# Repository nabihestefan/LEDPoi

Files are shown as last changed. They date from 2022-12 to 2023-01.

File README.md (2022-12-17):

# LED Prop Module
#### Nabih Estefan & Olivia Jo Bradley
Main Photo

For this project, we wanted to create a LED Prop Module by creating a battery powered PCB with a microcontroller, LEDs, an accelerometer, and buttons ,which would be enclosed in a clear capsule. 
Both of us are members of the Olin Fire Arts Club, and enjoy springing and performing with fire. Spinning fire is dangerous, and fire props are delicate, so we try to avoid practicing and trying new tricks with them. The solution to this is an LED version of the prop that is more durable and less dangerous than fire props, but is still exciting and aesthetic, so it can be used to perform with if desired.
This project requires a board with a battery management system, bright RGBW LEDs, an accelerometer (to react to the movements of spinning), a button to change modes, and a microcontroller that can run the code to make all of these work. As a stretch goal, we also wanted to add a bluetooth module to the board so we could connect and sync the colors and patterns of multiple modules. 

This repository holds the [Software](Software/), [Electrical](Electrical/) and [CAD](CAD/) files required to fabricate and assemble the board and casing designed by us and teh code to run the Prop Module. There is also a [images](images/) folder that contains images of the prototype and demo videos of the prop module in use. Finally, it also has our [Proposal](Proposal.pdf) and [Report](Report.pdf) detailing how we designed and built the Prop module.

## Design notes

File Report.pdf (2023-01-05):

# LED Prop Module

Eclectronics Final Report – Olivia Jo Bradley & Nabih Estefan

## Introduction

For this project, we wanted to create a LED Prop Module by creating a battery powered PCB with a microcontroller, LEDs, an accelerometer, and buttons ,which would be enclosed in a clear capsule.
Both of us are members of the Olin Fire Arts Club, and enjoy springing and performing with fire. Spinning fire is dangerous, and fire props are delicate, so we try to avoid practicing and trying new tricks with them. The solution to this is an LED version of the prop that is more durable and less dangerous than fire props, but is still exciting and aesthetic, so it can be used to perform with if desired.
This project requires a board with a battery management system, bright RGBW LEDs, an accelerometer (to react to the movements of spinning), a button to change modes, and a microcontroller that can run the code to make all of these work. As a stretch goal, we also wanted to add a bluetooth module to the board so we could connect and sync the colors and patterns of multiple modules.

## Selecting Parts

The process for speccing out the parts for our board was, unsurprisingly, very easy. The reason we say unsurprising is because most of the parts we needed for the board we chose through different projects we or Brad had done before. We based our project off of Mini-Project 3, including all of its components, so we focused on designing the 5 new sections we needed for the board:
1. Battery + Battery Management System
2. Wireless Module
3. Accelerometer
4. LEDs
5. Color Change Button
The first three were very easy because Brad showed us one of his old projects that also included these components, and were able to pull parts from that. The color change button was very easy to technically spec, so we focused on choosing a button that would fit the final aesthetic of the module, and went with an arcade style clear button. Finally, the LEDs took us the longest because we had to find LEDs that were bright enough but didn’t require an insane amount of voltage and/or current to run. We decided Neopixels were the best bet and eventually we found some side-lit ones that would allow us to shine lights on two sides of our board.

## Making the Schematic

Below, you can see the schematic we ended up designing for our LED Prop Module. The schematic work was surprisingly easy because of a couple of reasons, very similar to the reasons choosing parts was easy. For starters, we had a pretty big baseline with the Mini-Project 3. The other 5 big components that needed to be added to the board were:
1. Battery + Battery Management System
2. Wireless Module
3. Accelerometer
4. LEDs
5. Color Change Button
The first three were very easy to add because Brad helped us understand how they worked with one of his older schematics for a separate project that used these components, so we were able to just bring those over. The LEDs were also very easy to add because we only needed a single pin from the RP2040, and then we followed the schematic from the datasheet. Finally, the color change button was probably the easiest, since it’s just a button connected to the RP2040, and we have implemented surface mount versions in the past few mini projects. This meant that we were able to get a schematic done very fast, and were able to move onto the layout quickly.

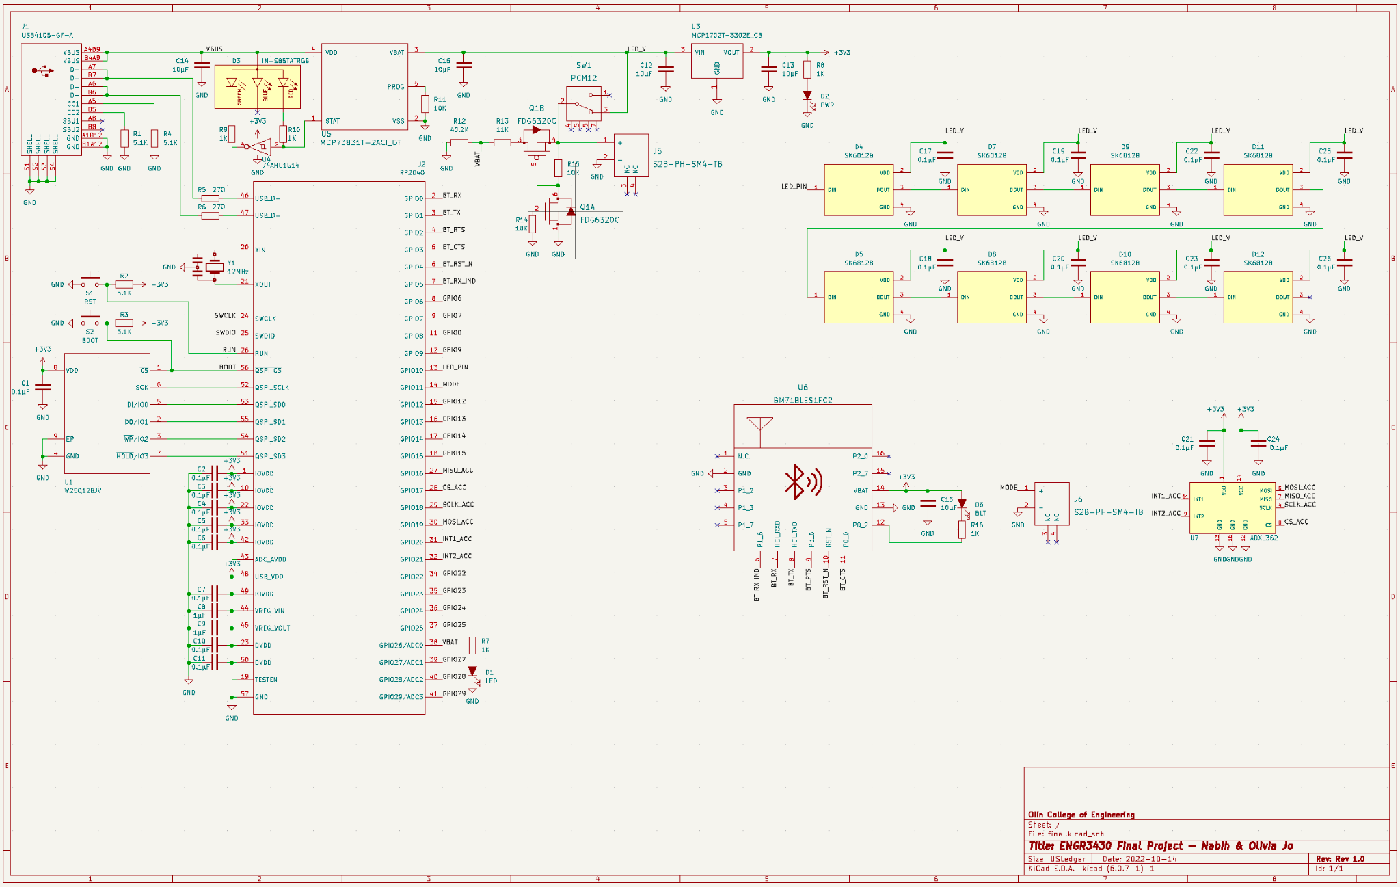
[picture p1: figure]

## Making the Layout

To the right you can see the final layout of our board. Once again, a lot of the general knowledge from Mini-Project 3 was brought onto this board, which resulted in it only really needing 2 revisions. Our first revision was getting the components down and fitting into the tiny board we gave ourselves. This board is very small because we didn’t want to have to handle a giant board for a prop module, since those are supposed to be nimble and small. Below the board you can see the diameter of our battery for context. While we were trying to make a smaller board, we did limit our minimum component size to 0603 components due to our experiences with Mini-Project 3.

## Building the Board

Once we got the physical boards and parts after thanksgiving,

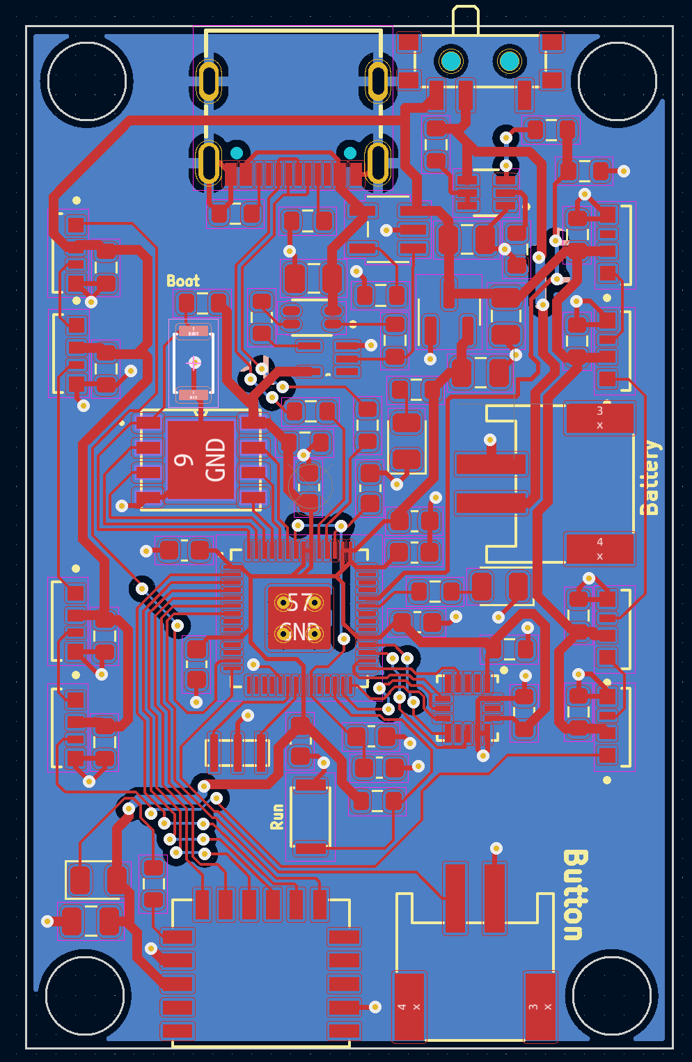
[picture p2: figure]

we set to building our board. We used the stencil that Brad provided, and created component sheets to organize our strips of parts. Our first iteration of the board had an unattached RP2040, and even though we tried to hand-solder it, we weren't able to get it to work. However,our second version worked perfectly, and we were able to run the LED code on it immediately!

## Code

Once we had a working board, there were 3 steps to the code development for the board. The first step was to get the LEDs to light up a single color which was extremely non-trivial since there is a micropython neopixel library which makes this extremely easy. The second step was getting the button to work to change colors. Theoretically this should have been non-trivial, and in code it was, but we had bought the wrong JST PH 2.0 connector cables for the button so we stalled here for a while. Finally, the third part was to implement the code to read data off of the accelerometer. This was extremely hard because the accelerometer works on a SPI bus, something neither of us had ever done. Eventually, we figured out the code we needed for it, but turns out that trying to compile the code needed through Thonny (the IDE we had been using to flash the RP2040 after it was the only working option in MP3) is basically impossible because there is no support for external libraries. Eventually we found an ADXL362 library that was perfect for what we needed, and it worked with Micropython! Sadly, we couldn’t install all the needed dependencies on the RP2040, so we had to turn back and look into the built in SPI library and try to get that one to work. We eventually got code that theoretically should work, but couldn’t figure out why it wasn’t and we ran out of time. Currently, the code in the github repo has the implementation for mode changes with the button and has theoretically working code for the accelerometer changing the blinking speed, we believe that the error with the accelerometer comes from the physical part on the board but we didn’t have time to assemble a new one. This means our Software folder currently has 2 versions: main.py and main_accel.py. The first one is the one we’re currently using that has no accelerometer code, and the second one contains the accelerometer code.

## Building the Enclosure

The enclosure for our LED Poi module needed to be semi transparent and contain all the necessary components, and hopefully easy to interact with (charge, press the button to change modes), connect to a rope handle of some sort, have a comparable weight to a fire prop, and be robust. To create the module, we instantly turned to 3d printing as it would allow us to use transparent materials, create unique shapes, and iterate quickly. We chose to make the enclosure out of clear resin, as it is a mostly transparent material, diffuses light nicely, and prints solid, providing more weight. We started with a traditional cylinder, making sure the button, board, and battery all fit. Once this was confirmed, we iterated and created a form with a more natural, rounded shape, as well as some modifications to make it print easier. The final enclosure can be seen below.

## Final State

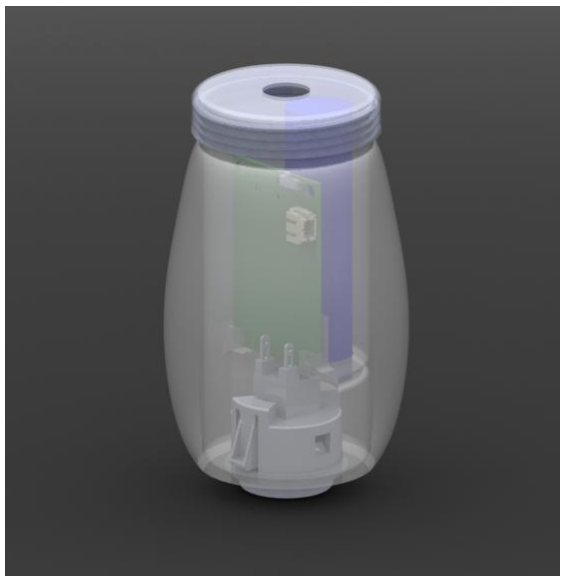
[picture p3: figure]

This all means that the final state of our project is a self-encased board with battery and button that has different blinking modes for spinning as a prop. Sadly, it has no accelerometer reaction, but assembling a new board would most likely solve this problem.

## Project Experience

We both had a lot of fun with this project, as we were both personally motivated and excited about the prop module we were making. We both came into this project wanting to become better at board assembly, as Mini Project 3 took far too many attempts. We were able to mostly complete this, as we were much better at connecting the RP2040 and only had to use 2 boards to get our first working board. We also got much better at selecting components, as we had to select and design for our LEDs using datasheets, something Olivia Jo was interested in doing, and she was able to complete this learning goal. While we were not able to complete all of our goals and stretch goals for the module, we were able to complete our learning goals, expand our knowledge, and create a working prototype.

The link to our github repository that contains all of the elements we created in this project is: https://github.com/nabihestefan/LEDPoi

This includes a schematic of our system, CAD renderings, our code, a bill of materials, photographs of our system, and our photographs and videos of our prototype.

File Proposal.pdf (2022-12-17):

Nabih Estefan & Olivia Jo Bradley

# LED Spinnable Prop

The plan is to build a board with the encasing around it that is able to act as a fully functioning LED Prop. This involves the following:

The Board will have an internal rechargeable battery, and a set of functions for different light modes for spinning with different sub-modes depending on acceleration, and a set of big LEDs that will be visible during the night.
Big features:
- Bright LEDs for display
- Different modes that can be changed using a easy-to-access button
- Rechargeable Battery
- Reaction to Accelerometer on light modes

Basically, this would be a board similar to the one in MP3 that has the following major components:

- USB-C Port
- Data transfer and maybe charging the battery?
- Microcontroller
- We can use the RP2040, might have to do some fun transistor things for LEDs
- An internal Singular Lipo battery
- 3.5-4.3V, 750mAh (or something close, this are the specs of existing LED props) (also hopefully rechargeable with the same USB-C port)
- An extra button that has two different types of clicks (hopefully, or at least two functionalities in press and hold)
- Or worst case one button and one switch, button for modes, switch for on/off
- A bigger set of RGB LEDs that have much higher illumination and can hopefully have different settings of brightness
- Dialight RBG Surface Mount LEDs probably, may use Neopixel instead, need to do some extra research before choosing
- A accelerometer that is able to differentiate between stable and moving poi so that the light modes will change
- 3 axis - Brad has a set of them we could use (Analog Devices)
- Stretch: Having a wireless module to communicate/sync two sets of poi
- RN4871

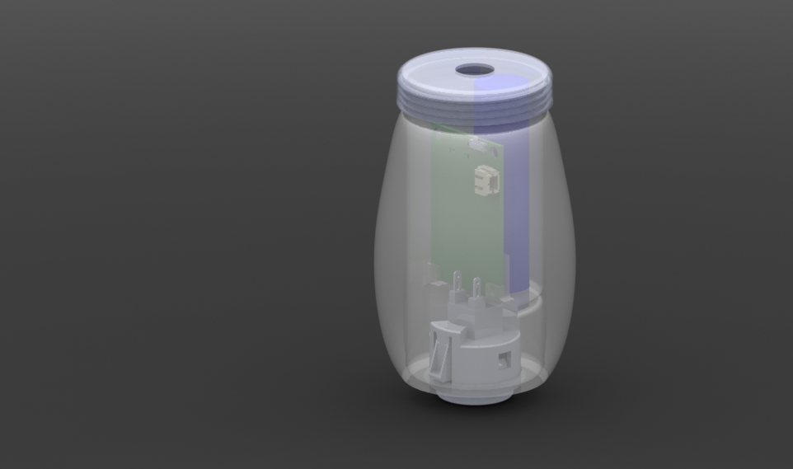
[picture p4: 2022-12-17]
Enclosure CAD/Render.JPG

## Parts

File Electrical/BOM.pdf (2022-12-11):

Description | Quantity in board | How many to order | Cost per part | Order cost | Manufacurer Part # | Catalog #
Arcade Button - 30mm Translucent Clear | 1 | 4 | $5.95 | $23.80 | Product ID: 471 | Adafruit
Arcade Button Quick-Connect Wire Pairs - 0.11" (10 pack) | 1 | 1 | $4.95 | $4.95 | Product ID: 1152 | Adafruit
Lithium Ion Cylindrical Battery - 3.7v 2200mAh | 1 | 4 | $9.95 | $39.80 | ICR18650 2200mAh 3.7V | Adafruit
NeoPixel Side-Light RGB LED w/ Integrated Driver Chip - 10-pack - SK6812B 4020 | 8 | 8 | $3.95 | $31.60 | Product ID: 4691 | Adafruit
0603 ±1% 1/10-W 1-kΩ resistor | 5 | 50 | N/A | N/A | RC0603FR-071KL | 311-1.00KHRCT-ND
0603 ±1% 1/10-W 27.4-Ω resistor | 2 | 20 | N/A | N/A | RC0603FR-0727R4L | 311-27.4HRCT-ND
0603 ±1% 1/10-W 5.1-kΩ resistor | 2 | 20 | N/A | N/A | ERJ-3EKF5101V | P5.10KHCT-ND
0603 25-V X7R 1-µF ceramic capacitor | 2 | 20 | N/A | N/A | CL10B105KA8NNNC | 1276-1184-1-ND
0603 50-V X7R 0.1-µF ceramic capacitor | 15 | 150 | N/A | N/A | CL10B104JB8NNNC | 1276-1033-1-ND
0805 25-V X5R 10-µF ceramic capacitor | 5 | 50 | N/A | N/A | CC0805KKX5R8BB106 | 311-1869-1-ND
0805 blue LED | 1 | 10 | N/A | N/A | LTST-C170TBKT | 160-1579-1-ND
0805 green LED | 1 | 10 | N/A | N/A | LTST-C170TGKT | 160-1887-1-ND
0805 red LED | 1 | 10 | N/A | N/A | LTST-C171KRKT | 160-1427-1-ND
3-axis accelerometer | 1 | 10 | N/A | N/A | ADXL362 | Adafruit
BM71BLES1FC2 Bluetooth Module | 1 | 10 | N/A | N/A | BM71BLES1FC2-0B04AA | BM71BLES1FC2-0B04AA-ND
Ceramic resonator 12.0000-MHz, 33pF | 1 | 10 | N/A | N/A | CSTNE12M0G55A000R0 | 490-17944-1-ND
MCP1702 3.3-V, 250-mA, LDO linear regulator, SOT-23-3 | 1 | 10 | N/A | N/A | MCP1702T-3302E/CB | MCP1702T-3302E/CBCT-ND
RP2040 microcontroller | 1 | 10 | N/A | N/A | SC0914(13) | 2648-SC0914(13)CT-ND
Tactile switch, SPST-NO, 0.02-A, 15-V | 1 | 10 | N/A | N/A | KTX 321 LHS | CKN10778CT-ND
Tactile switch, SPST-NO, 0.05-A, 12-V | 1 | 10 | N/A | N/A | TL3301AF160QJ | EG4374CT-ND
USB2.0 type C connector | 1 | 10 | N/A | N/A | USB4105-GF-A | 2073-USB4105-GF-ACT-ND
W25Q128JV 128-Mb, SPI/QSPI flash memory, 8WSON | 1 | 10 | N/A | N/A | W25Q128JVPIM TR | W25Q128JVPIMCT-ND
0603 ±1% 1/10-W 10-kΩ resistor | 3 | 30 | $0.02 | $0.63 | RC0603FR-0710KL | 311-10.0KHRTR-ND
0603 ±1% 1/10-W 11-kΩ resistor | 1 | 10 | $0.02 | $0.21 | RC0603FR-0711KL | 311-11.0KHRTR-ND
0603 ±1% 1/10-W 40.2-kΩ resistor | 1 | 10 | $0.02 | $0.21 | RC0603FR-1340K2L | 13-RC0603FR-1340K2LTR-ND
Battery IC for charging | 1 | 10 | $0.76 | $7.60 | MCP73831T-2ACI/OT | MCP73831T-2ACI/OTTR-ND
CMOS Inverter (74AHC1G14SE-7) | 1 | 10 | $0.24 | $2.39 | 74AHC1G14SE-7 | 74AHC1G14SE-7DITR-ND
JST-PH 2-Pin SMT Right Angle Connector | 2 | 20 | $0.47 | $9.48 | S2B-PH-SM4-TB(LF)(SN) | 455-1749-2-ND
MOSFET (PMGD290UCEAX) | 1 | 10 | $0.35 | $3.53 | PMGD290UCEAX | 1727-1354-2-ND
On-Off Switch (PCM12SMTR) | 1 | 10 | $0.93 | $9.31 | PCM12SMTR | 401-2016-2-ND
RGB LED Discrete | 1 | 10 | $0.33 | $3.30 | IN-S85TATRGB | 1830-1086-2-ND

1

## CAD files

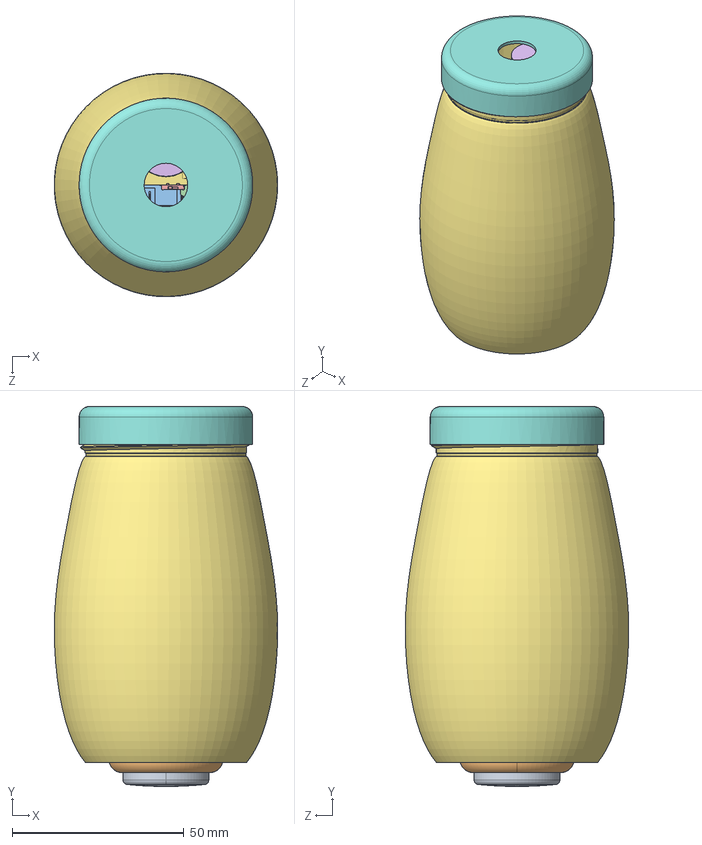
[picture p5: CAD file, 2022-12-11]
Enclosure CAD/FinalAssem.SLDASM
65.0 x 110.5 x 65.0 mm
top_cap.STEP
base.STEP
microswitch.STEP
JSTconnect.step
PCM12SMTR_PART1.stp
battery
CasingBottom
CasingTop

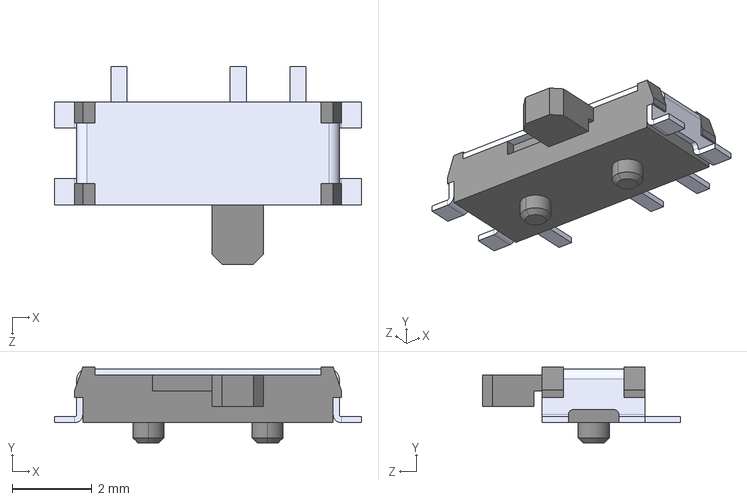
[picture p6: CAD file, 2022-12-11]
Electrical/Kicad/SnapEDA-Library/PCM12SMTR0.step
7.72 x 1.91 x 4.98 mm

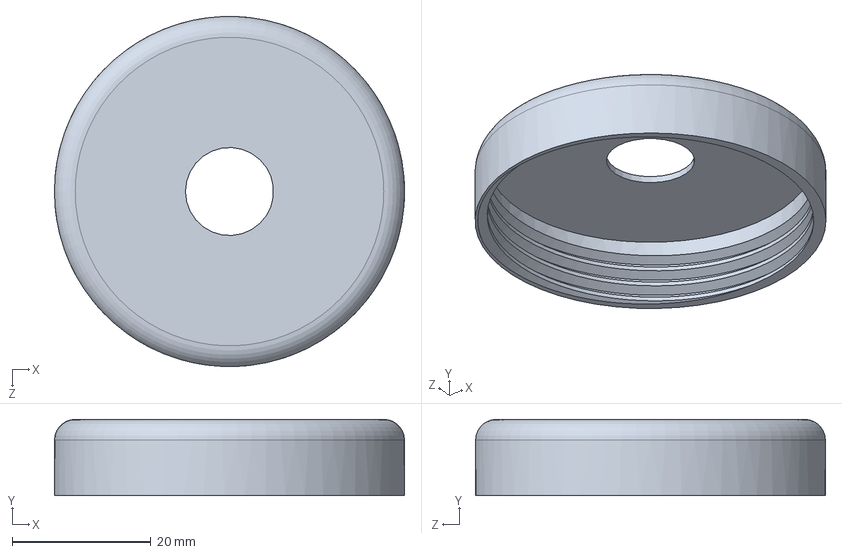
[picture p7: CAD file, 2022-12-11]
Enclosure CAD/CasingTop.SLDPRT
50.5 x 11.0 x 50.5 mm

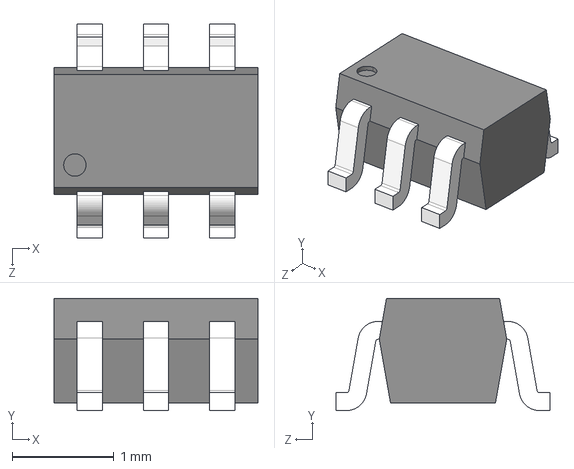
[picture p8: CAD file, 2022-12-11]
Electrical/Kicad/SnapEDA-Library/PMGD290UCEAX0.step
2.00 x 1.10 x 2.10 mm

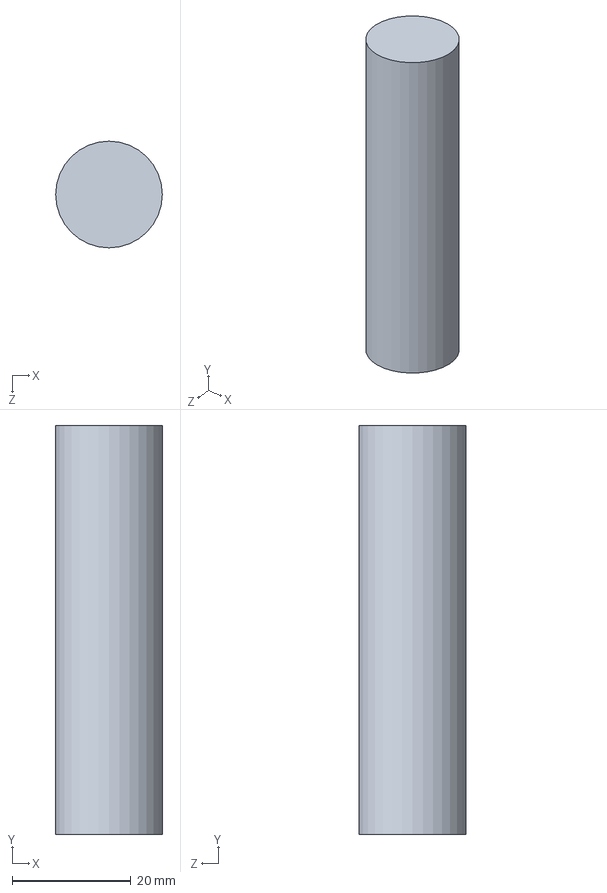
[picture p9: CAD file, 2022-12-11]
Enclosure CAD/battery.SLDPRT
18.0 x 69.0 x 18.0 mm

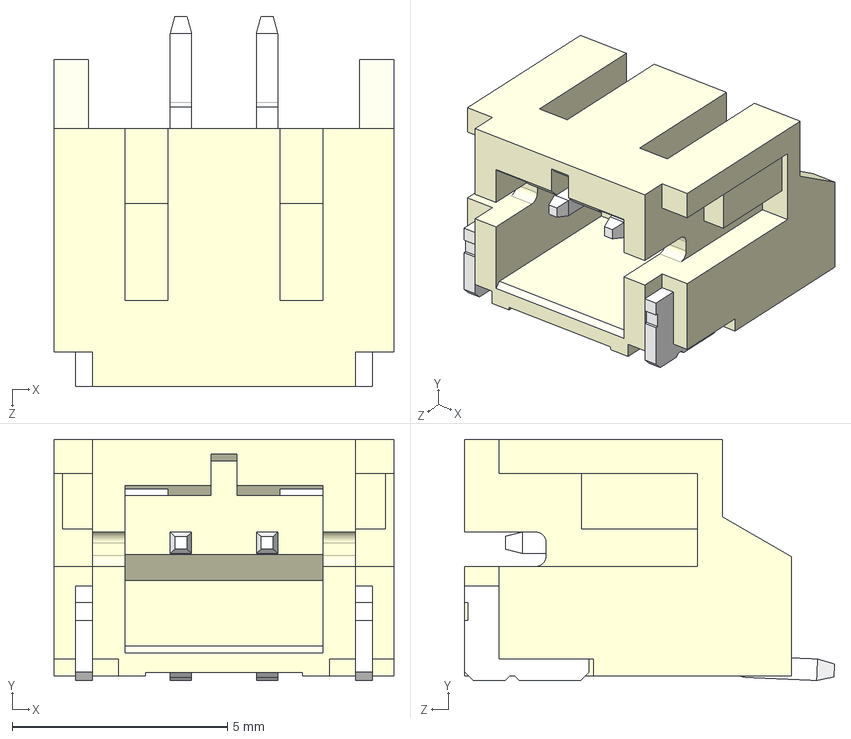
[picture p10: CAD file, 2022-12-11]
Enclosure CAD/JSTconnect.STEP
7.90 x 5.60 x 8.60 mm

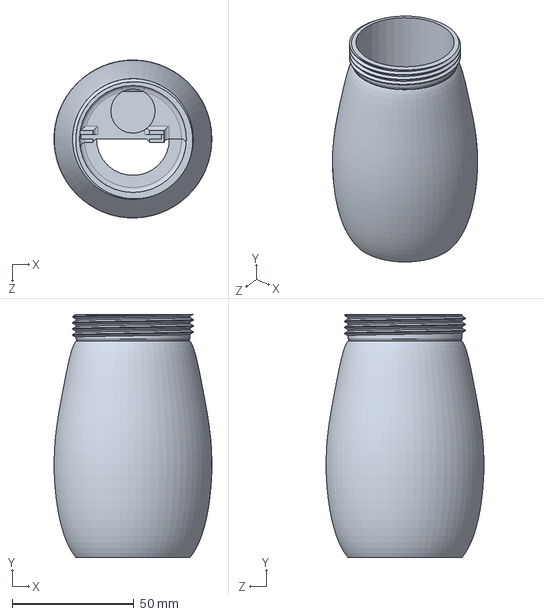
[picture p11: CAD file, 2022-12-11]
Enclosure CAD/CasingBottom.SLDPRT
65.0 x 100.0 x 65.0 mm

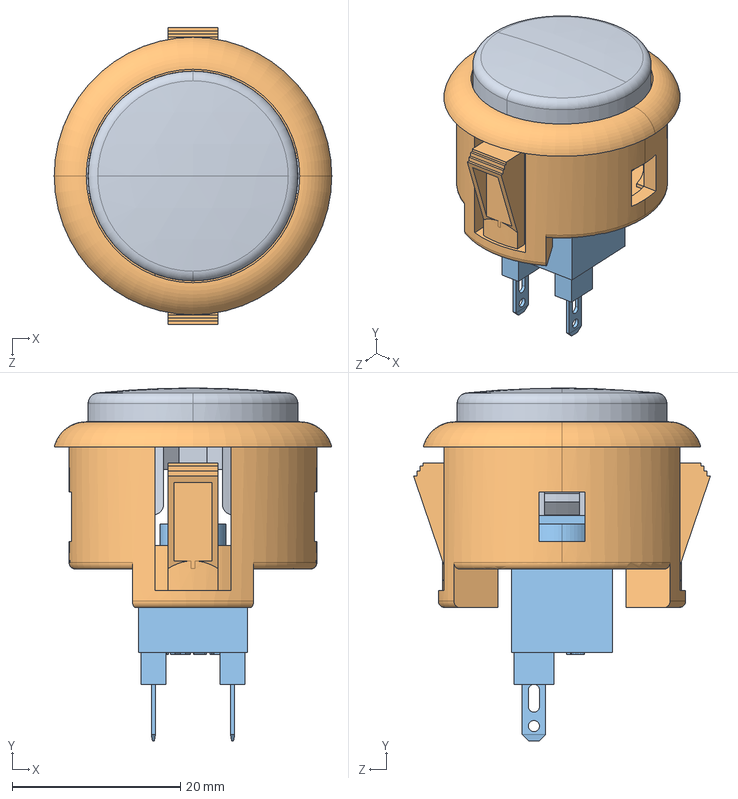
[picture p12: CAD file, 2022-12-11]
Enclosure CAD/30mm Button.STEP
33.0 x 42.0 x 35.3 mm
top_cap
base
microswitch

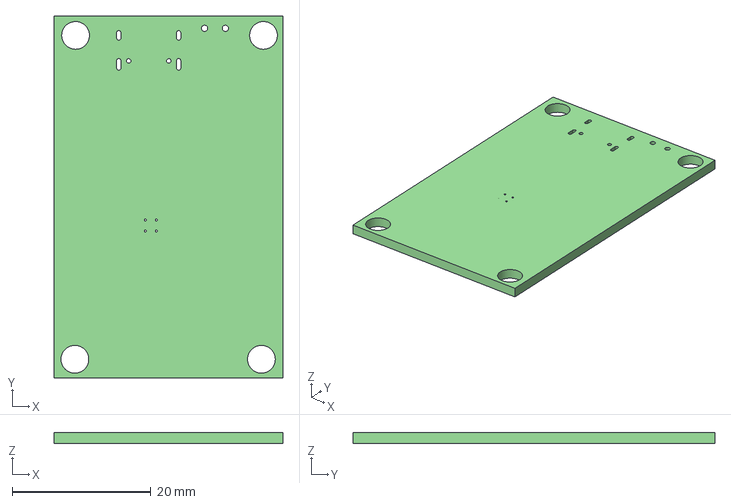
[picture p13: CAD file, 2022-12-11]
Enclosure CAD/final.step
33.0 x 52.2 x 1.60 mm

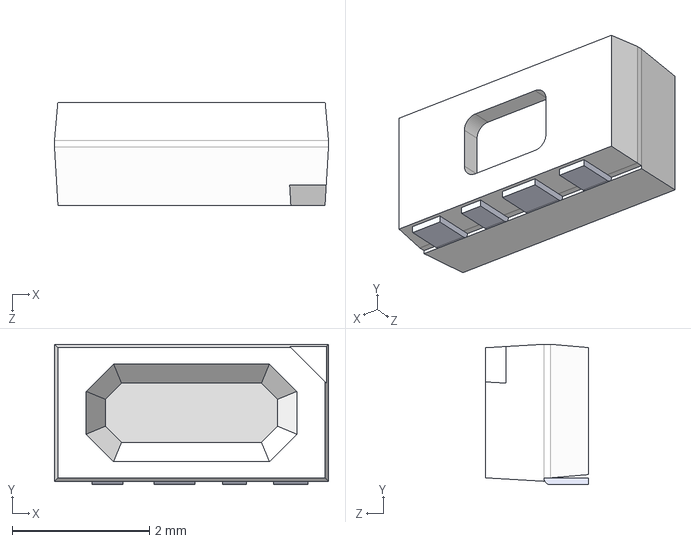
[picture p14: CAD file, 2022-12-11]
Electrical/Kicad/SnapEDA-Library/46910.step
4.00 x 2.05 x 1.50 mm

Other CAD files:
Enclosure CAD/OnOffSwitch.stp
Enclosure CAD/CasingBottom.STL
Enclosure CAD/CasingTop.STL

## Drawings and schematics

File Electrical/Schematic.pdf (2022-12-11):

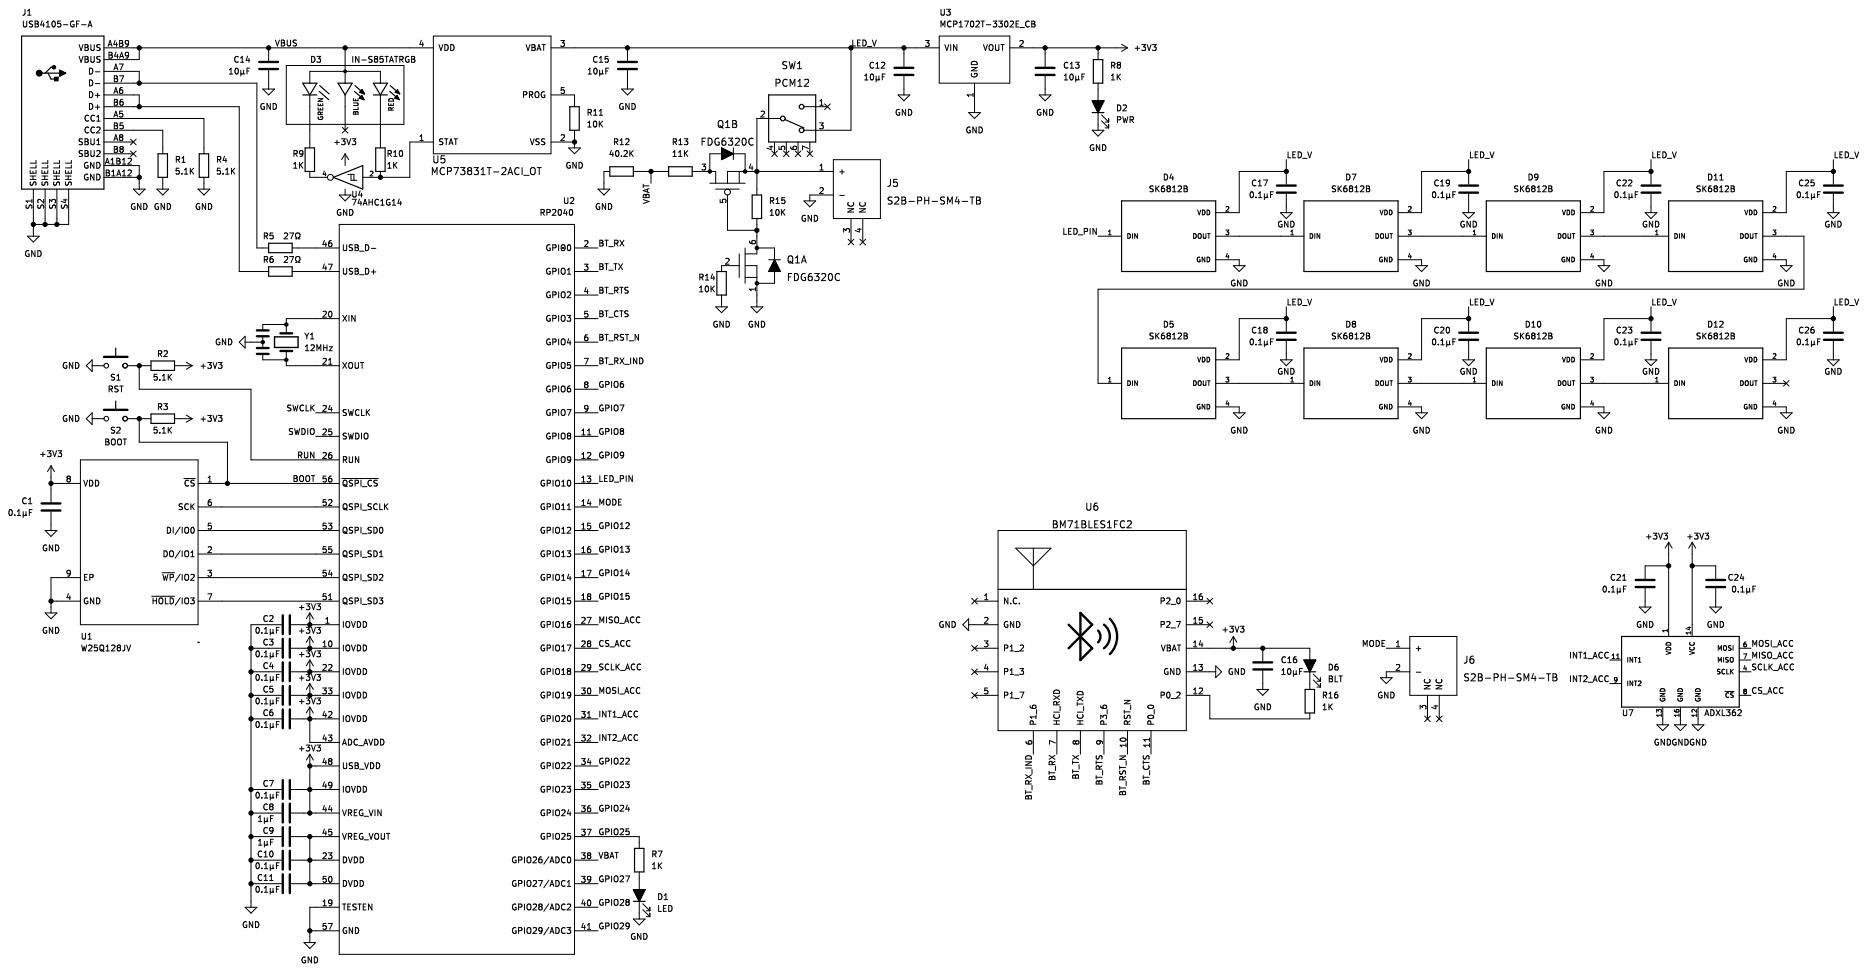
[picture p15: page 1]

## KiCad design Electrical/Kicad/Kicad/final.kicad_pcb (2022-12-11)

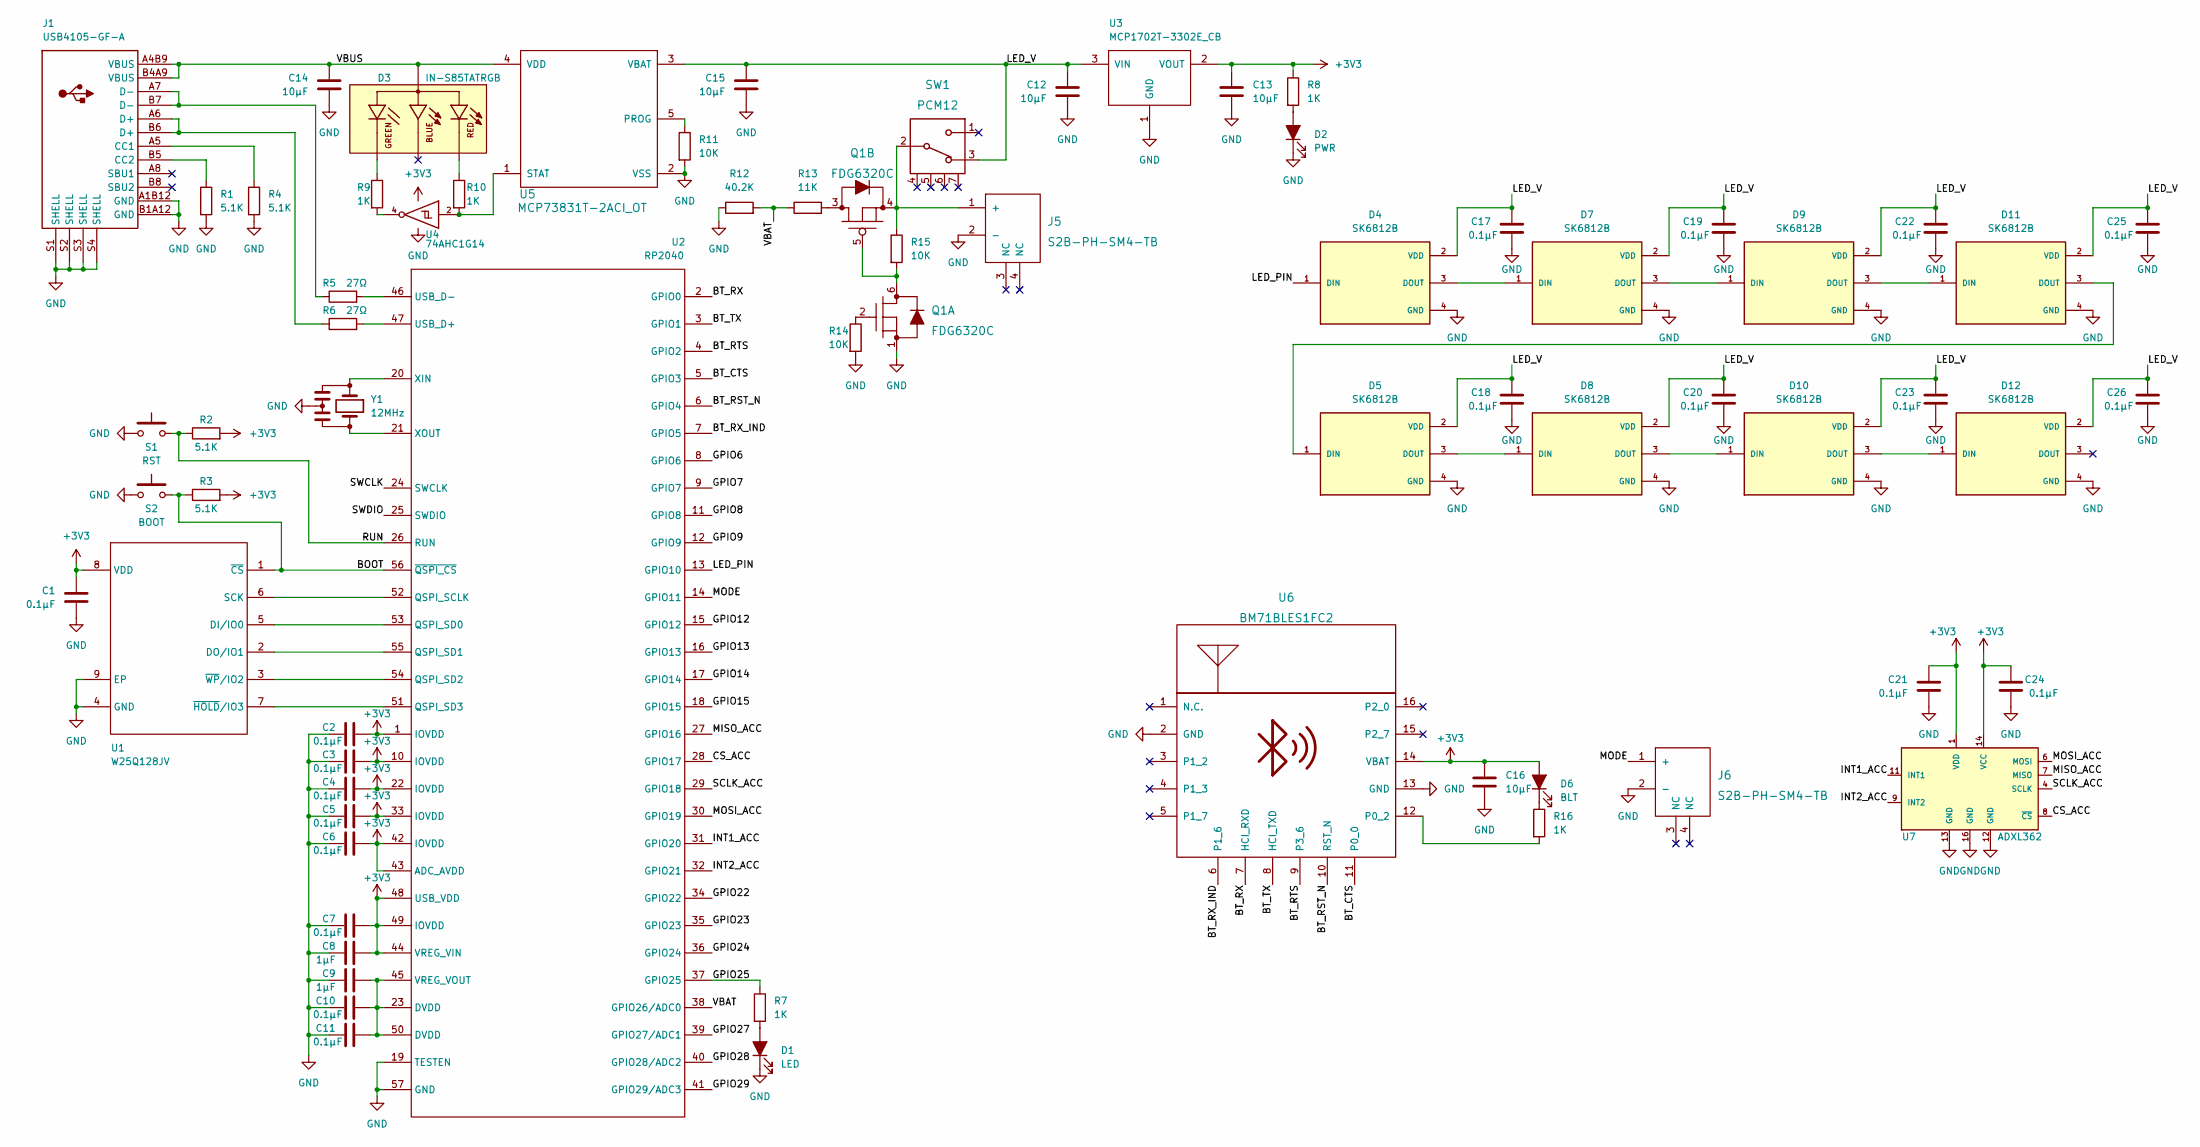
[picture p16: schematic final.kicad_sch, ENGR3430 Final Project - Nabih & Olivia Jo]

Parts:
C1, C17, C18, C19, C20, C21, C22, C23, C24, C25, C26: 0.1µF; R_0603_1608Metric
C2, C3, C4, C5, C6, C7, C10, C11: 0.1µF; C_0603_1608Metric
C8, C9: 1µF; C_0603_1608Metric
C12, C13, C14, C15, C16: 10µF; C_0805_2012Metric
D1: LED; LED_0805_2012Metric
D2: PWR; LED_0805_2012Metric
D3: IN-S85TATRGB; LEDSC70P200X125X110-4N; PARTREV 1.0
D4, D5, D7, D8, D9, D10, D11, D12: SK6812B; LED_4691; PARTREV 04
D6: BLT; LED_0805_2012Metric
J1: USB4105-GF-A
J5, J6: S2B-PH-SM4-TB
Q1: FDG6320C; SOT65P210X110-6N
R1, R2, R3, R4: 5.1K; R_0603_1608Metric
R5, R6: 27Ω; R_0603_1608Metric
R7, R8, R9, R10, R16: 1K; R_0603_1608Metric
R11, R14, R15: 10K; R_0603_1608Metric
R12: 40.2K; R_0603_1608Metric
R13: 11K; R_0603_1608Metric
S1: RST; KXT321LHS
S2: BOOT; KXT321LHS
SW1: PCM12
U1: W25Q128JV; MIC_WSON-8-M
U2: RP2040
U3: MCP1702T-3302E_CB; SOT-23
U4: 74AHC1G14; SOT65P210X110-5N
U5: MCP73831T-2ACI_OT; MCP73831T-2ACI&slash_OT
U6: BM71BLES1FC2
U7: ADXL362; TFLGA-16_3.3MMX3.1MM; MOUSER 584-ADXL362BCCZ-R7
Y1: 12MHz; CSTNE

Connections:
+3V3: C1.2, C2.1, C3.1, C4.1, C5.1, C6.1, C7.1, C8.1, C13.1, C16.1, C21.2, C24.2, D6.2 (A), R2.2, R3.2, R8.1, U1.8 (VDD), U2.1 (IOVDD), U2.10 (IOVDD), U2.22 (IOVDD), U2.33 (IOVDD), U2.42 (IOVDD), U2.43 (ADC_AVDD), U2.44 (VREG_VIN), U2.48 (USB_VDD), U2.49 (IOVDD), U3.2 (VOUT), U4.5 (VCC), U6.14 (VBAT), U7.1 (VDD), U7.14 (VCC)
/BOOT: R3.1, S2.2, U1.1 (~CS), U2.56 (~QSPI_CS)
/BT_CTS: U2.5 (GPIO3), U6.11 (P0_0)
/BT_RST_N: U2.6 (GPIO4), U6.10 (RST_N)
/BT_RTS: U2.4 (GPIO2), U6.9 (P3_6)
/BT_RX: U2.2 (GPIO0), U6.7 (HCI_RXD)
/BT_RX_IND: U2.7 (GPIO5), U6.6 (P1_6)
/BT_TX: U2.3 (GPIO1), U6.8 (HCI_TXD)
/CS_ACC: U2.28 (GPIO17), U7.8 (~CS)
/GPIO6: U2.8 (GPIO6)
/GPIO7: U2.9 (GPIO7)
/GPIO8: U2.11 (GPIO8)
/GPIO9: U2.12 (GPIO9)
/GPIO12: U2.15 (GPIO12)
/GPIO13: U2.16 (GPIO13)
/GPIO14: U2.17 (GPIO14)
/GPIO15: U2.18 (GPIO15)
/GPIO22: U2.34 (GPIO22)
/GPIO23: U2.35 (GPIO23)
/GPIO24: U2.36 (GPIO24)
/GPIO25: R7.1, U2.37 (GPIO25)
/GPIO27: U2.39 (GPIO27/ADC1)
/GPIO28: U2.40 (GPIO28/ADC2)
/GPIO29: U2.41 (GPIO29/ADC3)
/INT1_ACC: U2.31 (GPIO20), U7.11 (INT1)
/INT2_ACC: U2.32 (GPIO21), U7.9 (INT2)
/LED_PIN: D4.1 (DIN), U2.13 (GPIO10)
/LED_V: C12.2, C15.2, C17.2, C18.2, C19.2, C20.2, C22.2, C23.2, C25.2, C26.2, D4.2 (VDD), D5.2 (VDD), D7.2 (VDD), D8.2 (VDD), D9.2 (VDD), D10.2 (VDD), D11.2 (VDD), D12.2 (VDD), SW1.3, U3.3 (VIN), U5.3 (VBAT); also elsewhere on the board
/MISO_ACC: U2.27 (GPIO16), U7.7 (MISO)
/MODE: J6.1 (+), U2.14 (GPIO11)
/MOSI_ACC: U2.30 (GPIO19), U7.6 (MOSI)
/RUN: R2.1, S1.2, U2.26 (RUN)
/SCLK_ACC: U2.29 (GPIO18), U7.4 (SCLK)
/SWCLK: U2.24 (SWCLK)
/SWDIO: U2.25 (SWDIO)
/VBAT: R12.2, R13.1, U2.38 (GPIO26/ADC0)
/VBUS: C14.2, D3.3, J1.A4B9 (VBUS), J1.B4A9 (VBUS), U5.4 (VDD)
GND: C1.1, C2.2, C3.2, C4.2, C5.2, C6.2, C7.2, C8.2, C9.2, C10.2, C11.2, C12.1, C13.2, C14.1, C15.1, C16.2, C17.1, C18.1, C19.1, C20.1, C21.1, C22.1, C23.1, C24.1, C25.1, C26.1, D1.1 (K), D2.1 (K), D4.4 (GND), D5.4 (GND), D7.4 (GND), D8.4 (GND), D9.4 (GND), D10.4 (GND), D11.4 (GND), D12.4 (GND), J1.A1B12 (GND), J1.B1A12 (GND), J1.S1 (SHELL), J1.S2 (SHELL), J1.S3 (SHELL), J1.S4 (SHELL), J5.2 (-), J6.2 (-), Q1.1, R1.2, R4.2, R11.2, R12.1, R14.2, S1.1, S2.1, U1.4 (GND), U1.9 (EP), U2.19 (TESTEN), U2.57 (GND), U3.1 (GND), U4.3 (GND), U5.2 (VSS), U6.2 (GND), U6.13 (GND), U7.12 (GND), U7.13 (GND), U7.16 (GND), Y1.2; also elsewhere on the board
unnamed: C9.1, C10.1, C11.1, U2.23 (DVDD), U2.45 (VREG_VOUT), U2.50 (DVDD)
unnamed: D1.2 (A), R7.2
unnamed: D2.2 (A), R8.2
unnamed: D3.1, R10.1
unnamed: D3.2, R9.1
unnamed: D4.3 (DOUT), D7.1 (DIN)
unnamed 44: D5.3 (DOUT), D8.1 (DIN); also elsewhere on the board
unnamed: D6.1 (K), R16.1
unnamed: D7.3 (DOUT), D9.1 (DIN)
unnamed: D8.3 (DOUT), D10.1 (DIN)
unnamed: D10.3 (DOUT), D12.1 (DIN)
unnamed: D9.3 (DOUT), D11.1 (DIN)
unnamed 50: D5.1 (DIN), D11.3 (DOUT); also elsewhere on the board
unnamed 51: J1.A5 (CC1), R4.1; also elsewhere on the board
unnamed: J1.A6 (D+), J1.B6 (D+), R6.1
unnamed: J1.A7 (D-), J1.B7 (D-), R5.1
unnamed: J1.B5 (CC2), R1.1
unnamed: J5.1 (+), Q1.4, R15.1, SW1.2
unnamed: Q1.2, R14.1
unnamed: Q1.3, R13.2
unnamed: Q1.5, Q1.6, R15.2
unnamed: R5.2, U2.46 (USB_D-)
unnamed: R6.2, U2.47 (USB_D+)
unnamed: R9.2, U4.4
unnamed: R10.2, U4.2, U5.1 (STAT)
unnamed: R11.1, U5.5 (PROG)
unnamed: R16.2, U6.12 (P0_2)
unnamed: U1.2 (DO/IO1), U2.55 (QSPI_SD1)
unnamed: U1.3 (~WP/IO2), U2.54 (QSPI_SD2)
unnamed: U1.5 (DI/IO0), U2.53 (QSPI_SD0)
unnamed: U1.6 (SCK), U2.52 (QSPI_SCLK)
unnamed: U1.7 (~HOLD/IO3), U2.51 (QSPI_SD3)
unnamed: U2.20 (XIN), Y1.1
unnamed: U2.21 (XOUT), Y1.3

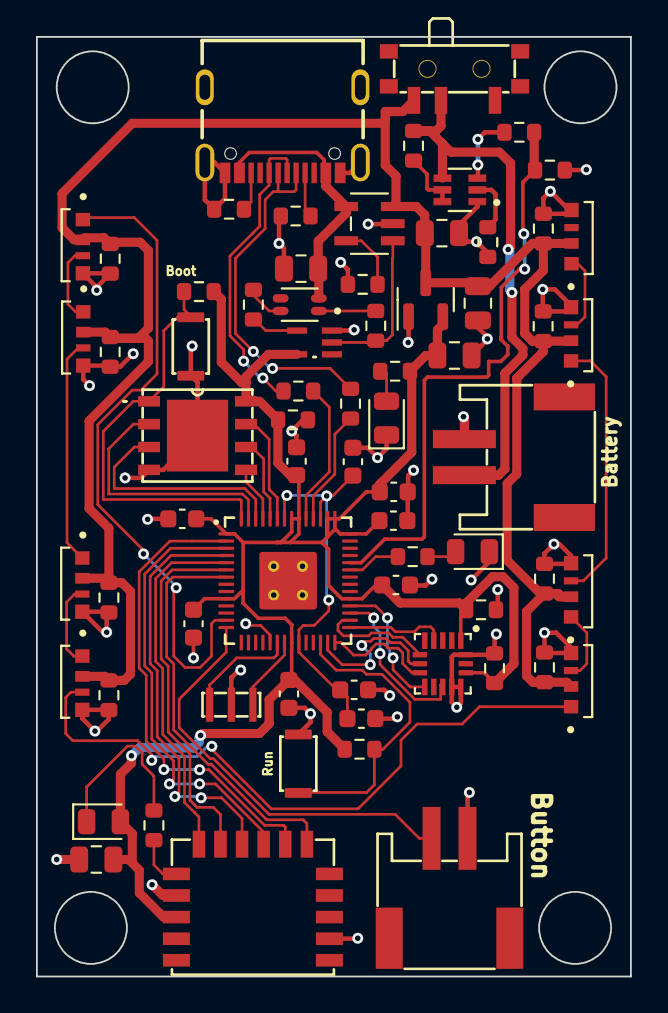
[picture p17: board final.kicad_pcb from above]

Board: 2 copper layers, 33.0 x 52.2 mm, 69 parts (0 on the bottom side), 56 nets.

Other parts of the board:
De: SK6812B; LED_4691
R}: 5.1K; R_0603_1608Metric

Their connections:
/LED_V: De.2 (VDD); also elsewhere on the board
GND: De.4 (GND), R}.2; also elsewhere on the board
unnamed 44: De.3 (DOUT); also elsewhere on the board
unnamed 50: De.1 (DIN); also elsewhere on the board
unnamed 51: R}.1; also elsewhere on the board

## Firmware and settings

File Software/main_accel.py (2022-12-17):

from machine import Pin, Timer, SPI
import neopixel
import sys

timer = Timer()

###############################################################################
# LEDS

# COLORS
RED = (255, 0, 0)
BLUE = (0, 50, 255)
GREEN = (0,255,0)
YELLOW = (255, 239, 0)
WHITE = (255, 255, 255)

COLORS = [[WHITE],
          [RED, WHITE],
          [BLUE,WHITE],
          [GREEN,WHITE],
          [YELLOW,WHITE],
          [RED,BLUE],
          [BLUE,GREEN],
          [BLUE,YELLOW],
          [RED, BLUE, GREEN]]

COLOR_IND = -1
COLOR_SUB_IND=0

# TIMES
STATIONARY_FREQ = 2
MOVING_FREQ = 4
MOVE_THRESHOLD = 1
NUM_PIXELS = 8

# PINS
NEOPIXEL_PIN = Pin(10, Pin.OUT)
LED_PIN = Pin(25, Pin.OUT)

# Strip setup
strip = neopixel.NeoPixel(NEOPIXEL_PIN, NUM_PIXELS)
strip.fill(COLORS[COLOR_IND][COLOR_SUB_IND])
strip.write()

def mainChange(timer):
    global COLORS
    global COLOR_IND
    global COLOR_SUB_IND
    COLOR_SUB_IND = (COLOR_SUB_IND+1)%len(COLORS[COLOR_IND])
    strip.fill(COLORS[COLOR_IND][COLOR_SUB_IND])
    strip.write()
                        
moving = False
timer.init(freq=STATIONARY_FREQ, mode=Timer.PERIODIC, callback=mainChange)

###############################################################################
# Button   
mode_button = machine.Pin(11, machine.Pin.IN, machine.Pin.PULL_UP)                

###############################################################################
# Accelerometer (not working)
# Assign chip select (CS) pin (and start it high)
cs = machine.Pin(17, machine.Pin.OUT)

# Initialize SPI
spi = machine.SPI(0,
                  baudrate=1000000,
                  polarity=1,
                  phase=1,
                  bits=8,
                  firstbit=machine.SPI.MSB,
                  sck=machine.Pin(18),
                  mosi=machine.Pin(19),
                  miso=machine.Pin(16))

REG_DEVID = 0x00
REG_X = 0x08
REG_Y = 0x09
REG_Z = 0x0A
DEVID = 0xAD

def reg_read(spi, cs, reg):
    
    # Construct message (set ~W bit high)
    msg = bytearray()
    msg.append(0x0B)
    msg.append(reg)
    
    # Send out SPI message and read
    cs.value(0)
    spi.write(msg)
    data = spi.read(1)
    cs.value(1)
    print("REG: ", reg, " MSG: ", msg, " DATA: ", data)
    
    return data

###############################################################################
# Main

# Read device ID to make sure that we can communicate with the ADXL343
# Part below is commented our since accelerometer not working
# Start CS pin high
cs.value(1)

# Workaround: perform throw-away read to make SCK idle high
reg_read(spi, cs, REG_DEVID)
data = reg_read(spi, cs, REG_DEVID)
if (data != bytearray((DEVID,))):
    print("ERROR: Could not communicate with ADXL343")
    sys.exit()


# Main program loop, repeats indefinitely
while True:

    if not mode_button.value():						# button pressed
        COLOR_IND = (COLOR_IND+1)%len(COLORS) 		# move on to next color

    x = reg_read(spi, cs, REG_X)
    y = reg_read(spi, cs, REG_Y)
    z = reg_read(spi, cs, REG_Z)

    accel_total = x * x + z * z + y * y
    
    if accel_total > MOVE_THRESHOLD and not moving:   # Poi is moving
        strip.fill(COLORS[GREEN_COLOR])
        strip.write()
        timer.deinit()
        timer.init(freq=MOVING_FREQ, mode=Timer.PERIODIC, callback=mainChange)
    elif moving:
        timer.deinit()
        timer.init(freq=STATIONARY_FREQ, mode=Timer.PERIODIC, callback=mainChange)

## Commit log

2022-12-11 Adding existing documents to repository
    [46910.step, PCM12SMTR0.step, PMGD290UCEAX0.step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]
2022-12-11 Enclosure CAD
    [30mm Button.STEP, CasingBottom.SLDPRT, CasingBottom.STL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]

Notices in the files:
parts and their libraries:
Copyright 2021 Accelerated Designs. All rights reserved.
